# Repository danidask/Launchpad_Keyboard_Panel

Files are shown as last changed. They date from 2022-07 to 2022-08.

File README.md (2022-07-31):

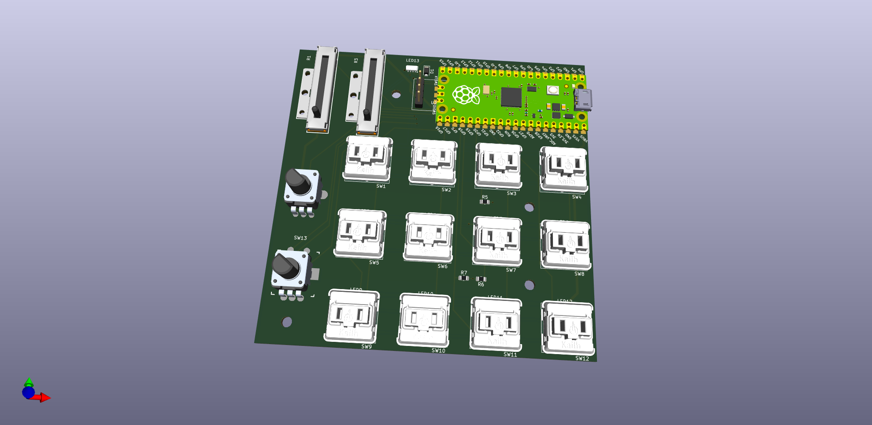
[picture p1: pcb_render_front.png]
PCB Render Front


# Specifications

- Size limit to the biggest size of low cost PCB manufacturers entry point PCBs (jlcpcb 100x100mm)
- Most of the components will be selected from https://jlcpcb.com/parts so they can be assembly by JLCPCB
- Other components will be sourced from cheap worldwide providers like aliexpress

See READMEs inside each folder

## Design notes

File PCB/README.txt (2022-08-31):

(see parent README.md)

# Requirements

Made with KiCad 6

## KiCad Plugins

https://github.com/bouni/kicad-jlcpcb-tools

# Track changes

[cadlab.io](https://cadlab.io/project/25849/)

# Specifications

(see parent README.md)

# Fabrication

The PCB is intended to be manufactured by JLCPCB so the outputs meet they requirements. Necessary files for manufacturing and assembly are in the jlcpcb folder

# BOM

LCSC parts are inside PCB\jlcpcb\assembly (to be assembly by jlcpcb or sourced from there and solder them manually)
- 12x Kailh choc Low profile Mechanical Switch, https://a.aliexpress.com/_uHRL47  (10 or 70)
- 12x Keycaps for Kailh choc, https://a.aliexpress.com/_uGXK51 (transparent-choc)
- 1x SSD1306 38x12mm OLED Display, https://a.aliexpress.com/_vNfBEr
- 1x RaspberryPi Pico, https://www.raspberrypi.com/products/raspberry-pi-pico/

# TODO

- Cover vias with soldermask
- Add diodes or limit resistors to keyboard matrix
- Power planes for 3.3v and 5v
- all pots (R1, R2, R3) swap GND and 3,3

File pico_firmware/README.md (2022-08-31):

# Getting started

[Raspberry Pico](https://www.raspberrypi.com/products/raspberry-pi-pico/) with [CircuitPython](https://circuitpython.org/board/raspberry_pi_pico/)

## versions
adafruit-circuitpython-raspberry_pi_pico-en_GB-7.3.2.uf2

# Needed ingredients:

- Read matrix keyboard
    https://learn.adafruit.com/key-pad-matrix-scanning-in-circuitpython/keymatrix
- USB HID emulating keyboard
    https://learn.adafruit.com/circuitpython-essentials/circuitpython-hid-keyboard-and-mouse
- read rotary encoder
    rotaryio
    https://learn.adafruit.com/rotary-encoder/hardware
- read analog inputs (potentiometers)
    https://learn.adafruit.com/circuitpython-essentials/circuitpython-analog-in
- drive neopixels
    https://learn.adafruit.com/circuitpython-essentials/circuitpython-neopixel
- oled display
    https://learn.adafruit.com/adafruit-oled-featherwing/python-usage

# References

- https://docs.circuitpython.org/en/7.1.x/
- https://learn.adafruit.com/circuitpython-essentials
- https://github.com/ZackFreedman/MiRage/

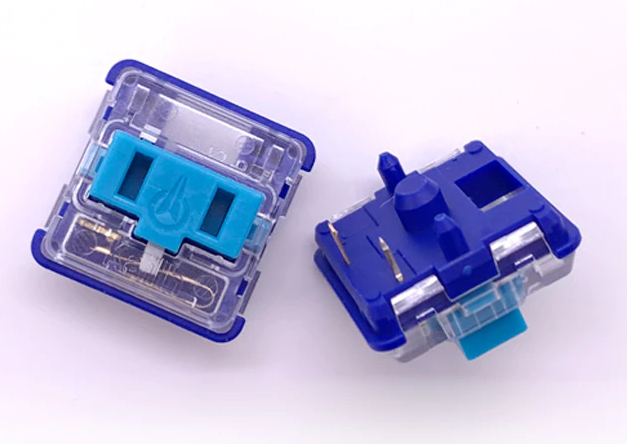
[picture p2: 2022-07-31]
datasheets/CPG135001D03_-_White_Clicky_Choc.png

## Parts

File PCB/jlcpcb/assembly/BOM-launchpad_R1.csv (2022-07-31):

Comment | Designator | Footprint | LCSC
PEC11R-4220F-S0012 | SW13 | SW-TH_PEC11R-4220F-S0012 | C143817
1K | R5,R6,R7 | R_0805_2012Metric_Pad1.20x1.40mm_HandSolder | C17513
RDC1022A05 | R1,R3 | RES-ADJ-TH_RDC1022A05 | C202389
RK09K1130A6S | R2 | RES-TH_RK09K1130A6S | C209770
XL-3528RGBW-WS2812B | LED1,LED10,LED11,LED12,LED13,LED2,LED3,LED4,LED5,LED6,LED7,LED8,LED9 | LED-SMD_4P-L3.5-W2.8-BR-1 | C2890364
D | D1 | D_SOD-123F | C64898
Kaihua PG1350 | SW12 | Kaihua_PG1350
Kaihua PG1350 | SW11 | Kaihua_PG1350
Kaihua PG1350 | SW10 | Kaihua_PG1350
Kaihua PG1350 | SW9 | Kaihua_PG1350
Kaihua PG1350 | SW8 | Kaihua_PG1350
Kaihua PG1350 | SW7 | Kaihua_PG1350
Kaihua PG1350 | SW6 | Kaihua_PG1350
Kaihua PG1350 | SW5 | Kaihua_PG1350
Kaihua PG1350 | SW4 | Kaihua_PG1350
Kaihua PG1350 | SW3 | Kaihua_PG1350
Kaihua PG1350 | SW1 | Kaihua_PG1350
Kaihua PG1350 | SW2 | Kaihua_PG1350
SSD1306 | U2 | SSD1306_38x12
RaspberryPi_Pico | U1 | RaspberryPi_Pico_SMD_TH

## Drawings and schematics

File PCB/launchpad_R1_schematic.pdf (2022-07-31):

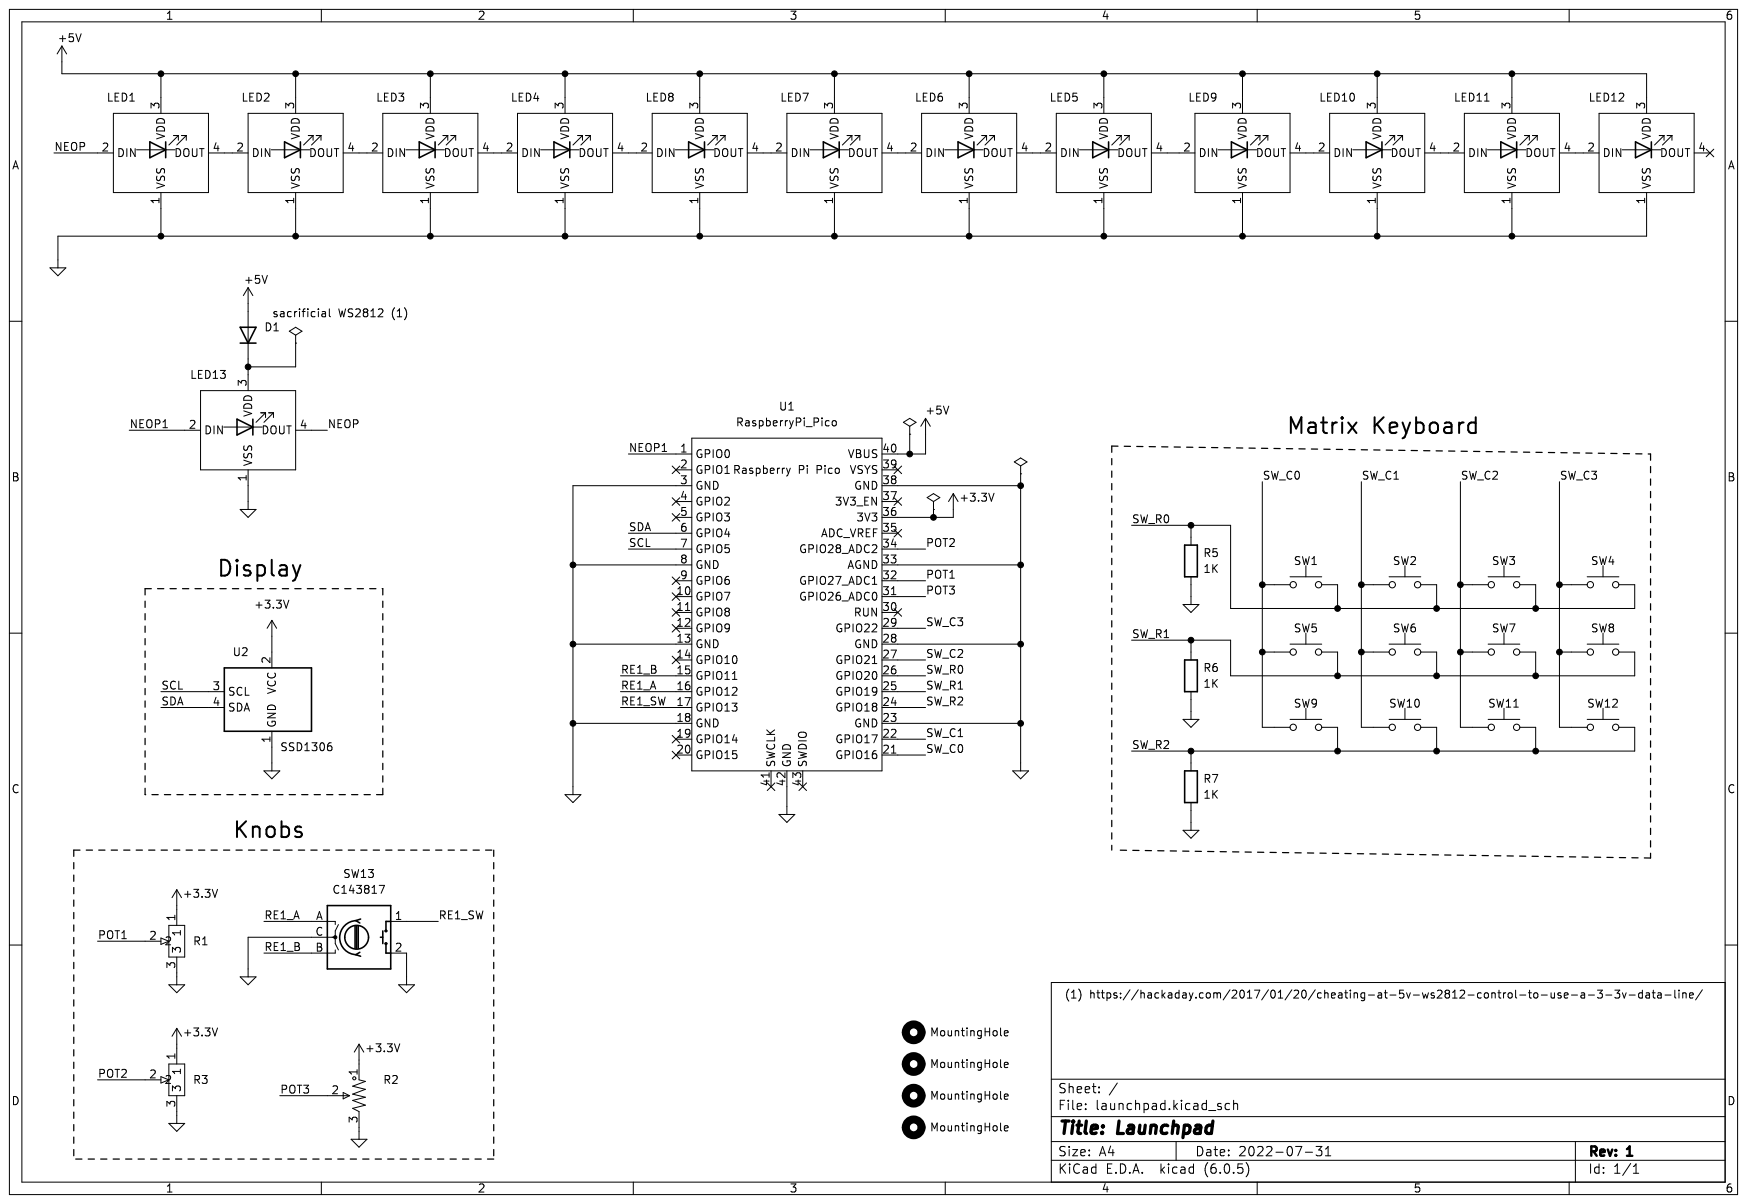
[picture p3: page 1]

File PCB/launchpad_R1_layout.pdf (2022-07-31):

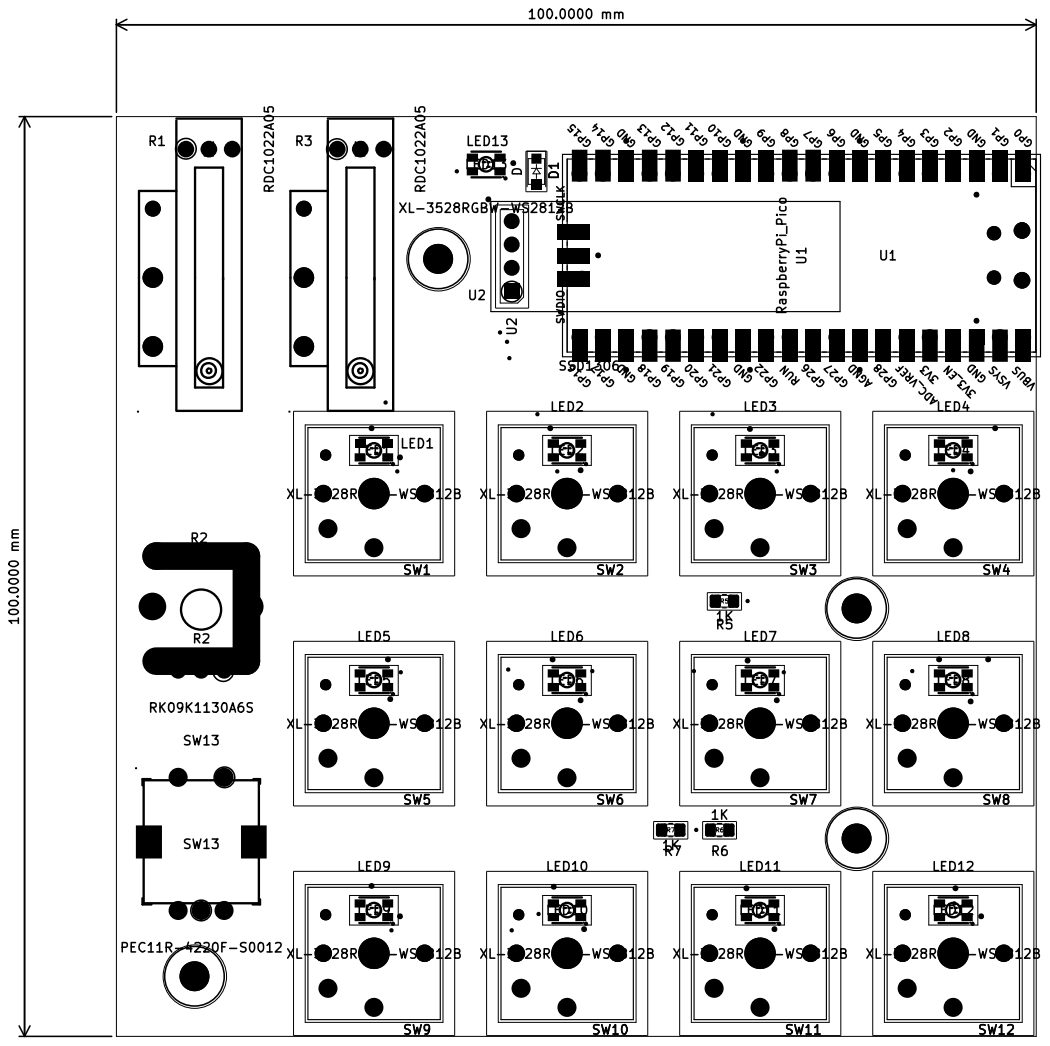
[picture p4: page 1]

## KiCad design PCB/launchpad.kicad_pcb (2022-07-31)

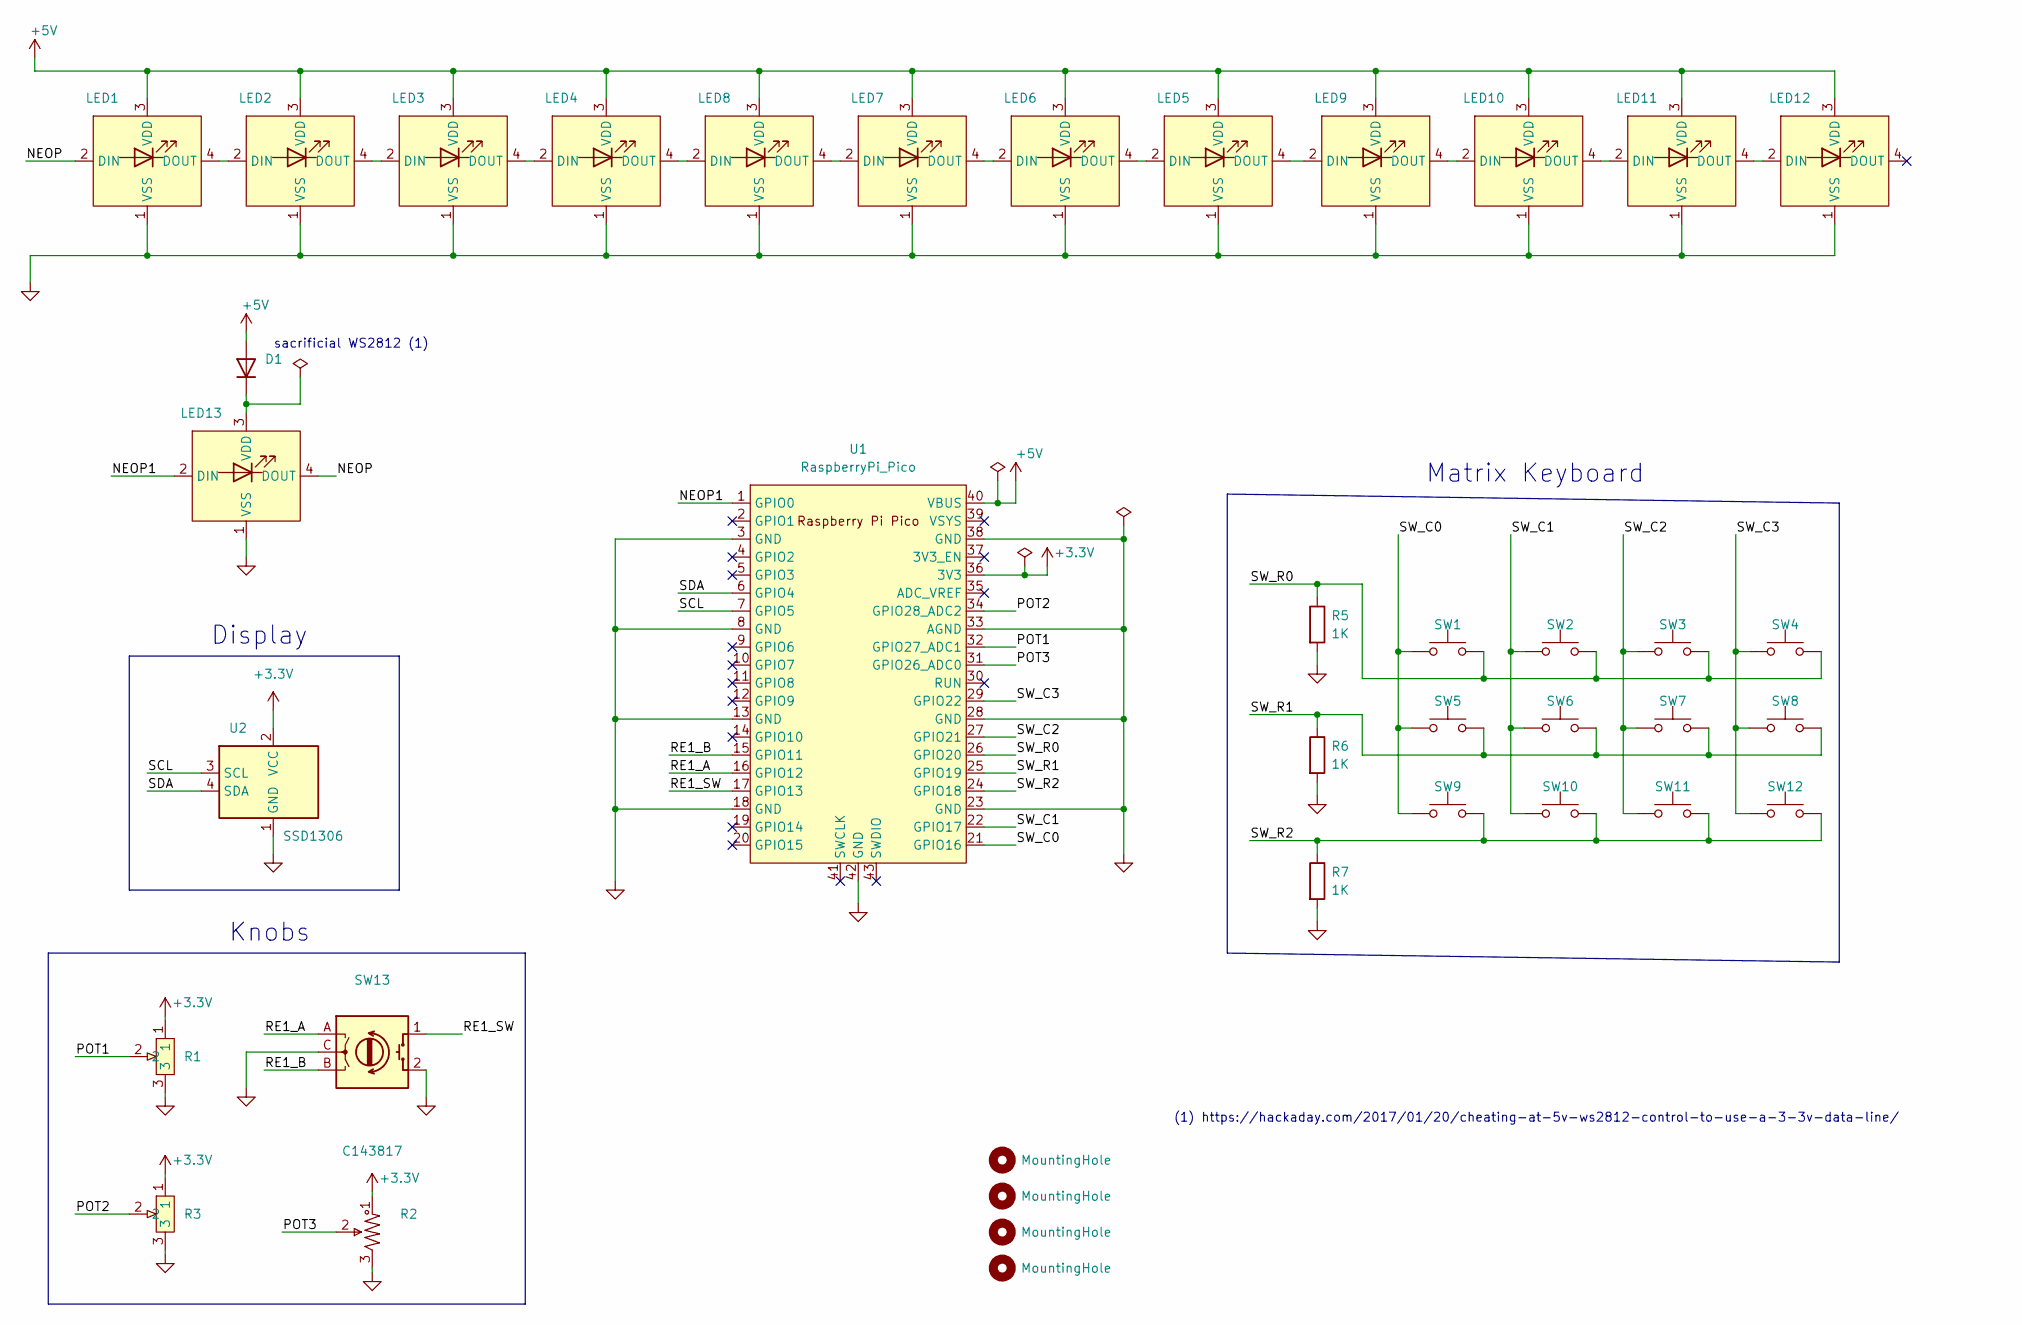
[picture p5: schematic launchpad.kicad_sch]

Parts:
D1: D; D_SOD-123F; MPN SM4007PL; LCSC C64898
H1, H2, H3, H4: MountingHole; MountingHole_3.2mm_M3
LED1, LED2, LED3, LED4, LED5, LED6, LED7, LED8, LED9, LED10, LED11, LED12, LED13: XL-3528RGBW-WS2812B; LED-SMD_4P-L3.5-W2.8-BR-1; LCSC Part C2890364
R1, R3: RDC1022A05; RES-ADJ-TH_RDC1022A05; LCSC Part C202389
R2: RK09K1130A6S; RES-TH_RK09K1130A6S; LCSC Part C209770
R5, R6, R7: 1K; R_0805_2012Metric_Pad1.20x1.40mm_HandSolder
SW1, SW2, SW3, SW4, SW5, SW6, SW7, SW8, SW9, SW10, SW11, SW12: Kaihua PG1350; Kaihua_PG1350
SW13: PEC11R-4220F-S0012; SW-TH_PEC11R-4220F-S0012; LCSC Part C143817
U1: RaspberryPi_Pico; RaspberryPi_Pico_SMD_TH
U2: SSD1306; SSD1306_38x12

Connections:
+3V3: R1.1, R2.1, R3.1, U1.36 (3V3), U2.2 (VCC)
+5V: D1.2 (A), LED1.3 (VDD), LED2.3 (VDD), LED3.3 (VDD), LED4.3 (VDD), LED5.3 (VDD), LED6.3 (VDD), LED7.3 (VDD), LED8.3 (VDD), LED9.3 (VDD), LED10.3 (VDD), LED11.3 (VDD), LED12.3 (VDD), U1.40 (VBUS)
/NEOP: LED1.2 (DIN), LED13.4 (DOUT)
/NEOP1: LED13.2 (DIN), U1.1 (GPIO0)
/POT1: R1.2, U1.32 (GPIO27_ADC1)
/POT2: R3.2, U1.34 (GPIO28_ADC2)
/POT3: R2.2, U1.31 (GPIO26_ADC0)
/RE1_A: SW13.A, U1.16 (GPIO12)
/RE1_B: SW13.B, U1.15 (GPIO11)
/RE1_SW: SW13.1 (S1), U1.17 (GPIO13)
/SCL: U1.7 (GPIO5), U2.3 (SCL)
/SDA: U1.6 (GPIO4), U2.4 (SDA)
/SW_C0: SW1.1 (A), SW5.1 (A), SW9.1 (A), U1.21 (GPIO16)
/SW_C1: SW2.1 (A), SW6.1 (A), SW10.1 (A), U1.22 (GPIO17)
/SW_C2: SW3.1 (A), SW7.1 (A), SW11.1 (A), U1.27 (GPIO21)
/SW_C3: SW4.1 (A), SW8.1 (A), SW12.1 (A), U1.29 (GPIO22)
/SW_R0: R5.1, SW1.2 (B), SW2.2 (B), SW3.2 (B), SW4.2 (B), U1.26 (GPIO20)
/SW_R1: R6.1, SW5.2 (B), SW6.2 (B), SW7.2 (B), SW8.2 (B), U1.25 (GPIO19)
/SW_R2: R7.1, SW9.2 (B), SW10.2 (B), SW11.2 (B), SW12.2 (B), U1.24 (GPIO18)
GND: LED1.1 (VSS), LED2.1 (VSS), LED3.1 (VSS), LED4.1 (VSS), LED5.1 (VSS), LED6.1 (VSS), LED7.1 (VSS), LED8.1 (VSS), LED9.1 (VSS), LED10.1 (VSS), LED11.1 (VSS), LED12.1 (VSS), LED13.1 (VSS), R1.3, R2.3, R3.3, R5.2, R6.2, R7.2, SW13.2 (S2), SW13.C, U1.3 (GND), U1.8 (GND), U1.13 (GND), U1.18 (GND), U1.23 (GND), U1.28 (GND), U1.33 (AGND), U1.38 (GND), U1.42 (GND), U2.1 (GND)
unnamed: D1.1 (K), LED13.3 (VDD)
unnamed: LED1.4 (DOUT), LED2.2 (DIN)
unnamed: LED2.4 (DOUT), LED3.2 (DIN)
unnamed: LED3.4 (DOUT), LED4.2 (DIN)
unnamed: LED4.4 (DOUT), LED8.2 (DIN)
unnamed: LED5.2 (DIN), LED6.4 (DOUT)
unnamed: LED5.4 (DOUT), LED9.2 (DIN)
unnamed: LED6.2 (DIN), LED7.4 (DOUT)
unnamed: LED7.2 (DIN), LED8.4 (DOUT)
unnamed: LED9.4 (DOUT), LED10.2 (DIN)
unnamed: LED10.4 (DOUT), LED11.2 (DIN)
unnamed: LED11.4 (DOUT), LED12.2 (DIN)

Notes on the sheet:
Knobs
sacrificial WS2812 (1)
Matrix Keyboard
Display
(1) https://hackaday.com/2017/01/20/cheating-at-5v-ws2812-control-to-use-a-3-3v-data-line/

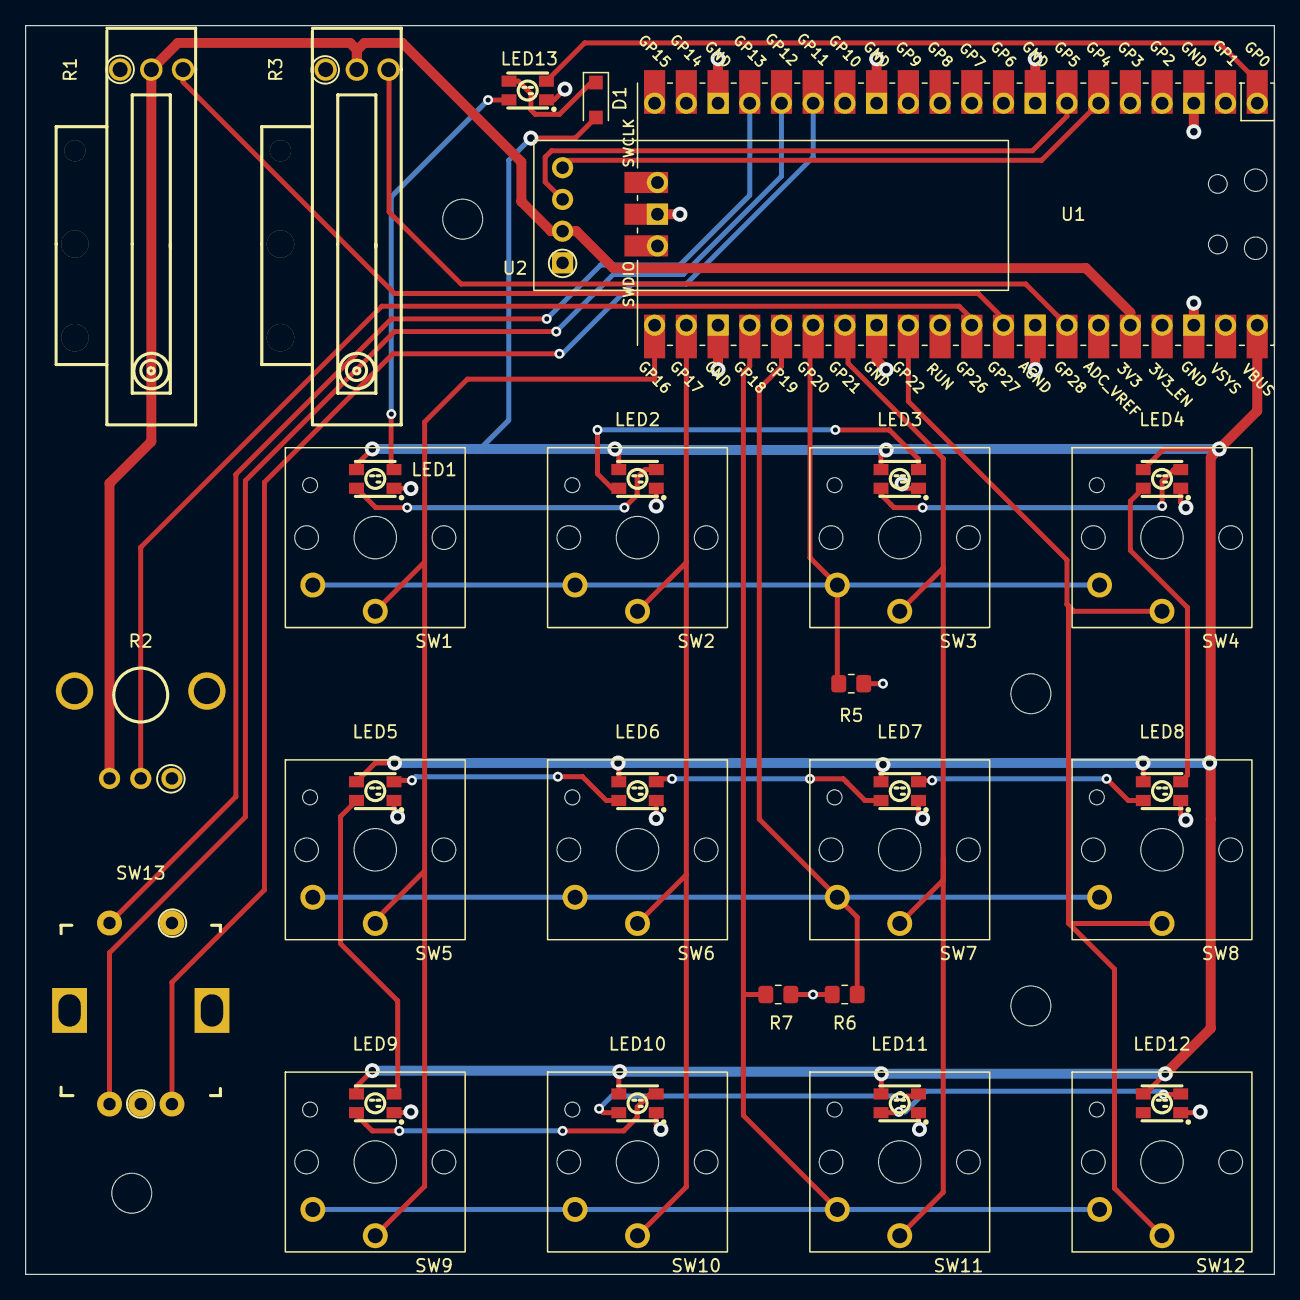
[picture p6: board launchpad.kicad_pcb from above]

Board: 2 copper layers, 100.0 x 100.0 mm, 39 parts (0 on the bottom side), 32 nets.

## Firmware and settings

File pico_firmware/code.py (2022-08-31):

from time import sleep
import board
import busio
import neopixel
from keypad import KeyMatrix
from digitalio import DigitalInOut, Direction, Pull
import rotaryio
from analogio import AnalogIn
import random
# import storage 
import displayio
import terminalio
from adafruit_display_text import label
import adafruit_displayio_ssd1306


class CustomDisplay:
    def __init__(self):
        displayio.release_displays()
        i2c = busio.I2C(board.GP5, board.GP4)
        display_bus = displayio.I2CDisplay(i2c, device_address=0x3c)
        self._display = adafruit_displayio_ssd1306.SSD1306(display_bus, width=128, height=32)
        self._splash = displayio.Group()
        self._text = ""
        self._text_changed = True

        # Make the display context
        self._display.show(self._splash)
        color_bitmap = displayio.Bitmap(128, 32, 1)
        color_palette = displayio.Palette(1)
        color_palette[0] = 0xFFFFFF  # White

        bg_sprite = displayio.TileGrid(color_bitmap, pixel_shader=color_palette, x=0, y=0)
        self._splash.append(bg_sprite)
        # Draw a smaller inner rectangle as text background
        inner_bitmap = displayio.Bitmap(118, 24, 1)
        inner_palette = displayio.Palette(1)
        inner_palette[0] = 0x000000  # Black
        inner_sprite = displayio.TileGrid(inner_bitmap, pixel_shader=inner_palette, x=5, y=4)
        self._splash.append(inner_sprite)    
        # Draw a label
        self._text_area = label.Label(terminalio.FONT, text=self._text, color=0xFFFFFF, x=28, y=15)
        self._splash.append(self._text_area)

    def text(self, text):
        self._text = text
        self._text_changed = True

    def update(self):
        if not self._text_changed:
            return
        self._text_changed = False
        self._text_area.text = self._text
        self._display.show(self._splash)

    def close(self):
        displayio.release_displays()

display = CustomDisplay()



pixels = neopixel.NeoPixel(board.GP0, 13, brightness=0.3, auto_write=True)  # does not need pixels.show() each time
l2b = (0, 1, 2, 3, 4, 8, 7, 6, 5, 9, 10, 11, 12)  # led index map with button index


# CUSTOM FUNCTIONS FOR POTENTIOMETERS ===============================

def change_brightness(val):
    # val 0.0 to 1.0
    pixels.brightness = round(val, 3)
    print(f"brightness {pixels.brightness}")

last_volume = 0
def change_volume(val):
    # val 0.0 to 1.0
    global last_volume
    volume = round(val*10)
    if volume == last_volume:
        return
    last_volume = volume
    m = f"vol {volume}"
    print(m)
    display.text(m)

last_example = 0
def change_example(val):
    # val 0.0 to 1.0
    global last_example
    disc_value = round(val*50)
    if disc_value == last_example:
        return
    last_example = disc_value
    m = f"exam {disc_value}"
    print(m)
    display.text(m)

pots = []
pots.append({
    "id": 1,
    'apin': AnalogIn(board.GP27_A1),
    'min': 3872,  # TODO get from configuration file
    'max': 62272,
    'threshold': 1200,
    'divisions': 10,
    'inverted': True,
    'trigger_at_start': False,
    'callback': change_volume,
})
pots.append({
    "id": 2,
    'apin': AnalogIn(board.GP28_A2),
    'min': 4256 + 450, # measured 4256
    'max': 62704 - 600, # measured 62704
    'threshold': 1200,
    'divisions': 20,
    'inverted': True,
    'trigger_at_start': True,
    'callback': change_brightness,    
})
pots.append({
    "id": 3,
    'apin': AnalogIn(board.GP26_A0),
    'min': 144 + 450,  # measured 144
    'max': 65520 - 450, # measured 65520
    'threshold': 900,
    'divisions': 10,
    'inverted': True,
    'trigger_at_start': False,
    'callback': change_example,
})

# configure pots
for pot in pots:
    sleep(0.01)
    if pot['trigger_at_start']:
        pot['last_value'] = 99999
    else:
        pot['last_value'] = pot['apin'].value


encoders = []
encoders.append({
    "id": 1,
    'obj': rotaryio.IncrementalEncoder(board.GP12, board.GP11),
    'last_position': 0
})

# configure and fill last_position
for encoder in encoders:
    encoder['obj'].divisor = 2
    encoder['last_position'] = encoder['obj'].position


km = KeyMatrix(
    row_pins=(board.GP20, board.GP19, board.GP18),
    column_pins=(board.GP16, board.GP17, board.GP21, board.GP22),
    # interval=0.050,  # debounce
)


def check_pots():
    for pot in pots:
        value = pot['apin'].value
        if abs(value - pot['last_value']) > pot['threshold']:
            # v = value * 3.3 / 65536
            pot['last_value'] = value
            d = (value - pot['min'])/(pot['max'] - pot['min'])
            if d<0:
                d=0.0
            elif d>1:
                d=1.0
            if pot['inverted']:
                d=1.0-d
            print(f"pot id {pot['id']}: raw {value} norm {d:.3f}")
            # display.text(f"p{pot['id']}: {d:.2f}")
            pot['callback'](d)


def check_encoders():
    for encoder in encoders:
        position = encoder['obj'].position
        if position != encoder['last_position']:
            encoder['last_position'] = position
            print(f"encoder id{encoder['id']}: {position}")
            display.text(f"e{encoder['id']}: {position}")


def check_keyboard():
    while 1:
        event = km.events.get()
        if not event:
            break
        # print(event)
        print(f"{event.key_number} {event.pressed} {event.released} {event.timestamp} ")
        display.text(f"key {event.key_number+1} {event.pressed}")
        if event.pressed:
            r = random.randrange(0,256)
            g = random.randrange(0,256)
            b = random.randrange(0,256)
            i = l2b[event.key_number+1]
            pixels[i] = (r,g,b)


def calibrate_pots_limits():
    for pot in pots:
        pot['min'] = 65536
        pot['max'] = 0
    print_resoult = True
    while True:
        for pot in pots:
            sleep(0.05)
            value = pot['apin'].value
            if value < pot['min']:
                pot['min'] = value
                print_resoult=True
            elif value > pot['max']:
                pot['max'] = value
                print_resoult=True
        if print_resoult:
            s = ""
            for pot in pots:
                s+=f"id{pot['id']} min {pot['min']} max {pot['max']}, "
            print(s)
            print_resoult=False

def calibrate_pots_threshold():
    for pot in pots:
        pot['m'] = 0

    while True:
        s = ""
        for pot in pots:
            r = pot['apin'].value
            for i in range(50):
                sleep(0.005)
                v = pot['apin'].value
                if abs(v-r) > pot['m']:
                    pot['m']=abs(v-r)
            s+=f"{pot['id']}: {pot['m']}, "
        print(s)
        sleep(5)


pixels[0] = (0, 128, 0)  # status LED

# calibrate_pots_limits()
# calibrate_pots_threshold()
counter = 0
# try:
while True:
    check_pots()
    check_encoders()
    check_keyboard()
    if counter%5 == 0:
        display.update()
    counter+=1
    sleep(0.01)
    # except MemoryError:  # because of the display
# except:
#     pixels[0] = (128, 0, 0)
#     pixels.brightness = 0.25
# displayio.release_displays()

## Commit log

2022-07-31 r1 almost finish
    [Checklist_R1.csv, launchpad.kicad_pcb, launchpad.kicad_sch]
2022-07-31 R1 sent to fab
    [BOM-launchpad_R1.csv, Checklist_R1.csv, launchpad.kicad_pcb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]
2022-07-31 rename library
    [launchpad.kicad_pcb, launchpad.kicad_sch]
2022-07-31 PCB 3D model
    [launchpad.kicad_pcb]
